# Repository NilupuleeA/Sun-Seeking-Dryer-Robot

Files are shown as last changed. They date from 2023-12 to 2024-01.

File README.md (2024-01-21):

# Sun-Seeking-Dryer-Robot

This is a group project done under the module EN1190 Engineering Design project, Semester 2 of the Department of Electronic and Telecommunication Engineering.

1. Introduction
   
- This dryer is designed to transform the conventional approach to drying spices, shoes, and other items in both rural and urban households. By integrating an advanced sun tracking system using Light-Dependent Resistors (LDR) sensors, this dryer autonomously follows the sun's movement throughout the day, ensuring optimal exposure to sunlight for efficient and eco-friendly drying.

2. Key Features
- Automatic Sun Tracking: The dryer utilizes cutting-edge LDR sensors to precisely follow the sun's position, optimizing the drying process without manual intervention.

- Energy-Efficient: This system utilizes sunlight, a renewable energy source, reducing environmental impact and providing a sustainable solution for households.

- Effortless Drying: The Sun Seeking Dryer simplifies the drying process, making it accessible to everyone in the community.

https://github.com/NilupuleeA/Sun-Seeking-Dryer-Robot/assets/153465850/cd82b63b-5a86-44f9-a196-c00ea6002b2a

Final_Product

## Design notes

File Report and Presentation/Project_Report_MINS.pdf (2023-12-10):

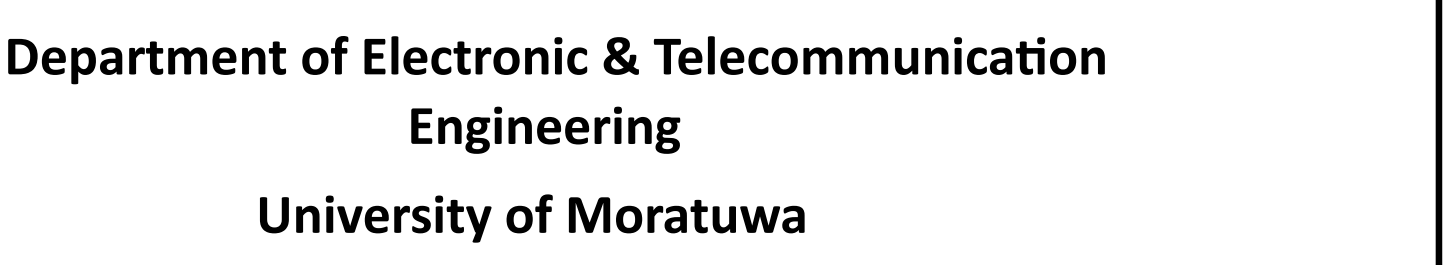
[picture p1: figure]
Engineering; University of Moratuwa

## Department of Electronic & Telecommunication

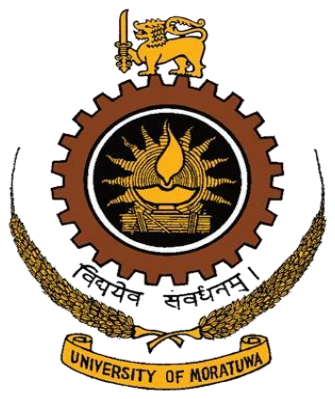
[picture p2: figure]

## EN 1190 - Engineering Design Project

Final Project Report

## Sun Seeking Dryer Robot – Team MINS

Group members:

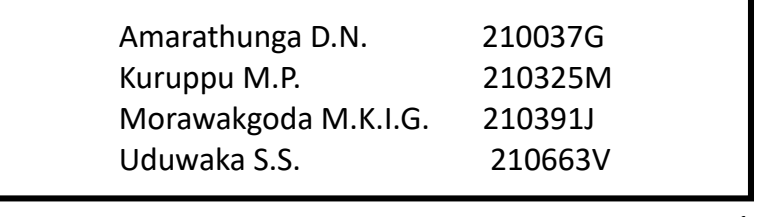
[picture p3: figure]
Amarathunga D.N.; Kuruppu M.P.; Morawakgoda M.K.I.G.; Uduwaka S.S.

# INDEX

## 1 Introduction

In today's fast-paced world, where busy schedules and unpredictable weather conditions often hinder household chores, the need for efficient and automated solutions becomes evident. Drying various materials, such as seeds, spices, clothes, and shoes, using sunlight, is often time-consuming and unreliable due to weather fluctuations. To address this challenge, our project aims to develop an automatic sun-seeking dryer that optimizes the drying process through sun tracking technology.

### 1.1 Problem description

Households, especially those in rural areas with limited access to electricity, face difficulties in efficiently drying materials. Conventional sunlight-based drying methods are subject to weather conditions and require manual intervention for effective drying. Our project seeks to create an innovative solution that eliminates these challenges by automating the drying process.

### 1.2 Motivation

The motivation behind this project lies in enhancing the overall quality of life for individuals by providing a solution that optimizes an essential domestic task. By automating the drying process, we aim to relieve the burdens faced by households, enabling them to focus on other tasks. This project aligns with the broader societal push toward sustainable practices and resource conservation, as the sun-seeking dryer utilizes a renewable energy source.

We conducted a survey in the initial stage to gather some information about the drying process. After analyzing a sample of 100 people, we have concluded some justifications for the project.

According to the survey most of the people know the traditional methods of drying materials. It was obvious that most of the people use different drying methods to dry their clothes, shoes, and seeds in their day-to-today lives. By analyzing the survey, we could conclude that the drying methods are essential for the daily works because most of the people who responded to the survey have submitted that they are using the methods of drying for domestic purposes very frequently. The below pie chart shows how often people dry materials for domestic purposes according to the survey. Also, we decided to collect data about the issues the people are facing with the traditional methods of drying materials. According to the results, the main issues of the traditional methods are the rain, cloudy days, and the changes of humidity. Here are the results that we got. A waste of time, taking longer time than expected, bad smell, reducing the quality of the final product, not being able to dry properly, inability to attend at the right time and to the right standard, were the main issues they have been faced.

### 1.3 Our Solution

The team of MINS decided to take the burden on to their shoulders and decides to find a solution. The sun seeking dryer robot is the ultimate result of this. When the sun seeking dryer robot is kept in a position where the intensity of the sunlight is low it moves to a position where the intensity of sunlight is higher than the previous place.

## 2 Technical feasibilities

Our project of designing an automatic system that follows the sun to dry materials is technically feasible. This system can be built using a set of sensors, microcontrollers, and mechanical components such as motors, wheels etc.

### 2.1 Sensors

The system would require a few essential sensors, including LDRs, to monitor the sunlight intensity and ultrasonic sensors to identify barriers on the way. These sensors are readily available and affordable in the market, and the required performance targets can be met without any difficulty.

For this system we used 4 LDR to cover the four directions. Also, we used 2 ultrasonic sensors in the forward and backward directions to identify the barriers when moving.

### 2.2 Microcontroller

The microcontroller is the brain of the system that controls the entire operation of the automatic driving system. Microcontrollers are widely used in various industrial applications, and they can handle the necessary calculations and data processing required for this project. Moreover, the availability and affordability of microcontrollers make it a feasible option.

For this system we used ATMEGA 328 micro controller.

### 2.3 Mechanical components

The mechanical components, including motors and wheels, are also readily available and can be used to ensure that the system moves smoothly and accurately. These components can be controlled by the microcontroller, which ensures that the system moves in the right direction and at the right speed.

In conclusion, the technical feasibility of the proposed project of designing an automatic system that follows the sun to dry materials is high, and all the necessary resources and performance targets are readily available and can be met.

## 3 Product Architecture

### 3.1 Block Diagram Abstraction of the Device

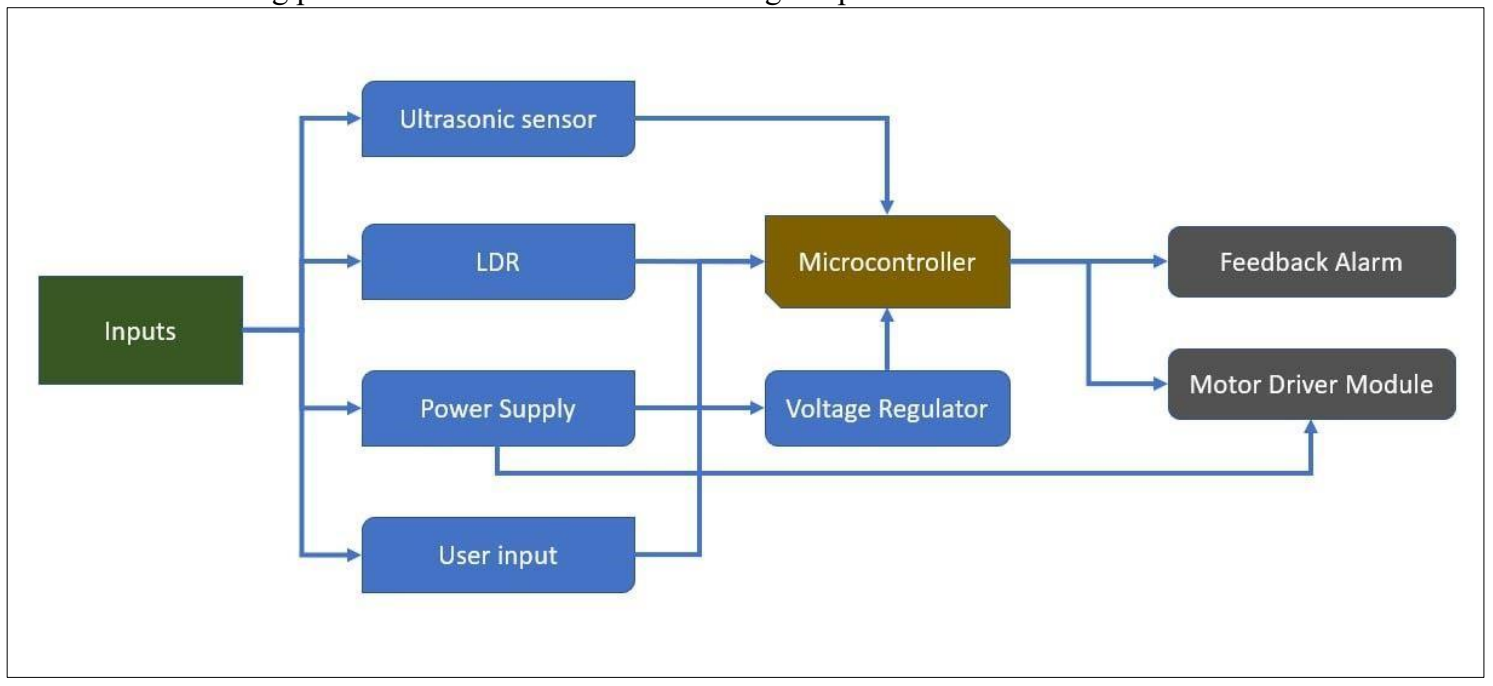
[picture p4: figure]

The following product architecture was used during the process.

### 3.2 Functionality of the Blocks

### - Power Supply Management

The power supply management for this device utilizes two 3.7V rechargeable batteries, which are regulated down to 5V using a voltage regulator.

### - User Input

An on/off switch is manually controlled by the user to switch the entire system on and off.

### - LDR

The device is equipped with four LDRs that are used to detect and measure the intensity of sunlight in all four directions. This information is used to make decisions about the device's operation and to adjust its movements and functions, as necessary.

### - Ultrasonic Sensor

Two ultrasonic sensors are also incorporated into the device to measure the distance to obstacles and prevent collisions while the device is in use.

### - Microcontroller

The microcontroller is responsible for processing all these inputs and controlling the device's overall operation.

### - Feedback Alarm

If all sides are dark, a feedback alarm is triggered to inform the user of this situation. For this purpose we used a buzzer.

### - Motor Driver Module

The device is equipped with a motor driver module that allows system to rotate its wheels and move throughout its environment.

## 4 Product enclosure

### 4.1 Solid work design

The enclosure was designed by using ‘Solid Works’. It is made by the material ‘PLA’

The enclosure contains 2 major parts. They are the top and the bottom part. The bottom part was design in such a way that it contains holes for four wheels, two ultrasonic sensors, four tubes for the LDR, switch, charging port.

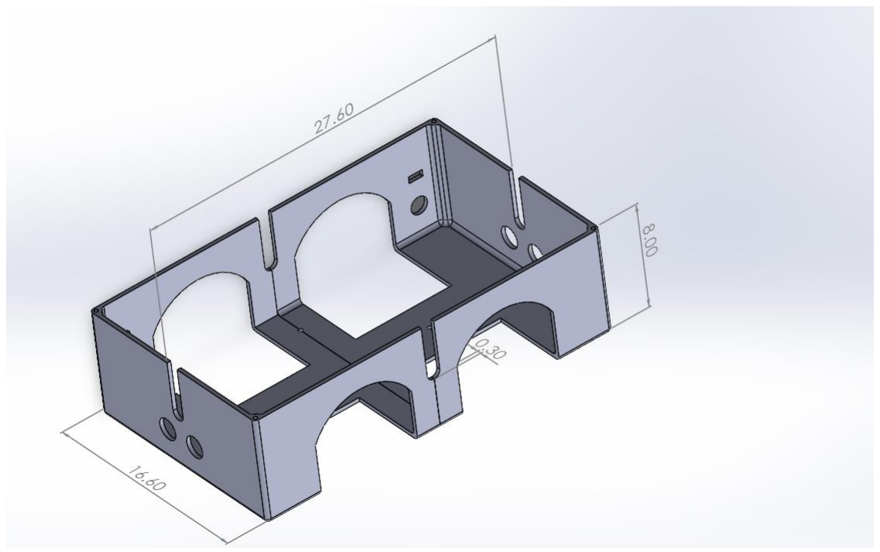
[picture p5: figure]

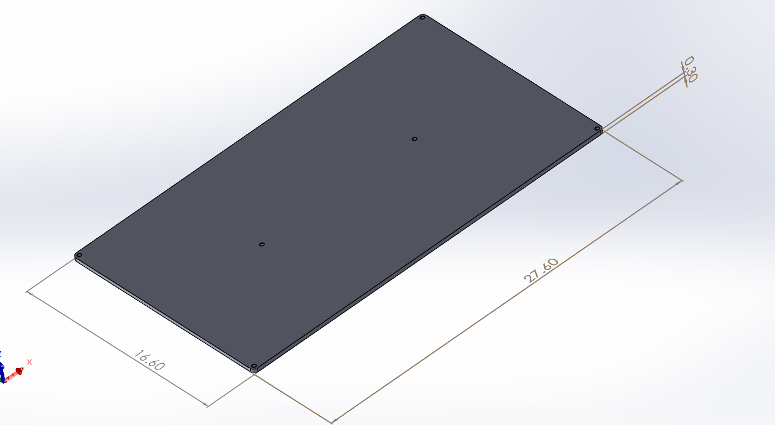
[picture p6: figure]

The tray to hold materials such as grains was made by a light metal to enhance the tendency for absorbing sunlight to make the drying process more rapid than the normal way. The reason for not selecting iron as the material for designing the tray is the tendency of iron to corrode when imposing sunlight, wind, and humidity climatic parameters and it will cause to reduce the quality of the drying material.

Also, we had to keep a distance between the metal tray and the top part in order to avoid unwanted heating of the circuit.

The following diagram shows how the final design looks like.

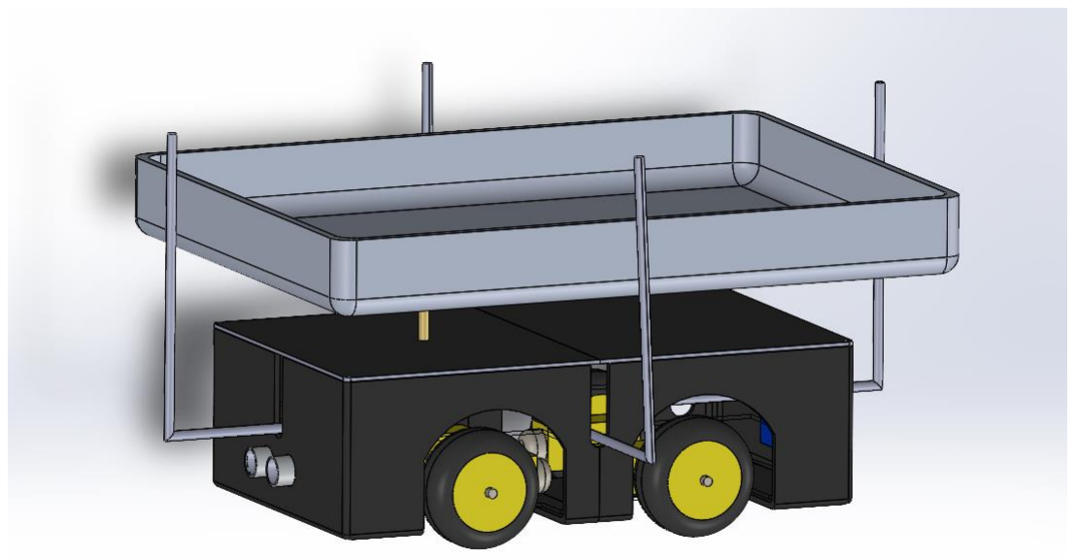
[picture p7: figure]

## 5 Circuit Diagram

### 5.1 Altium Schematic Diagram

The following schematic diagram has been created using Altium.

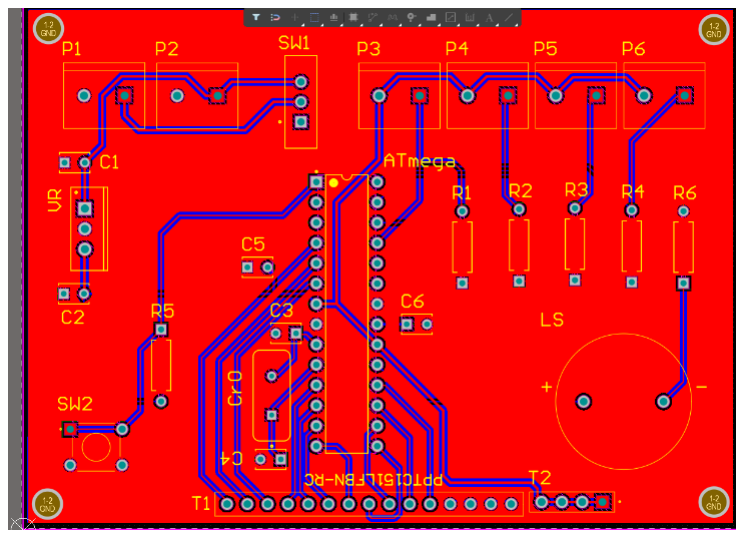
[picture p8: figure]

After Soldering the components

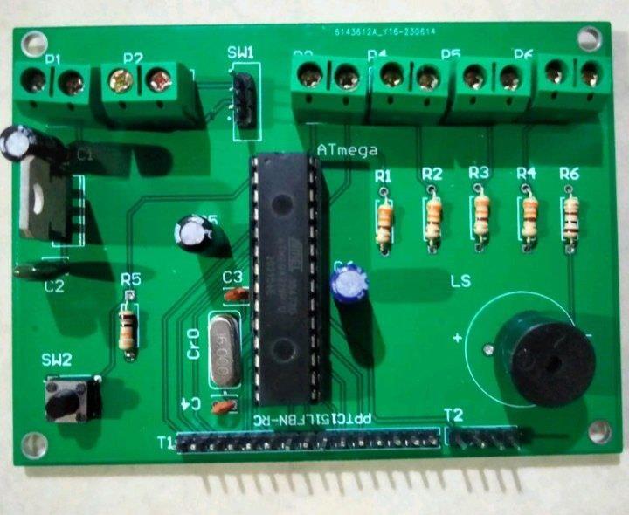
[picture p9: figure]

### 5.2 ATmega Circuit Stimulation

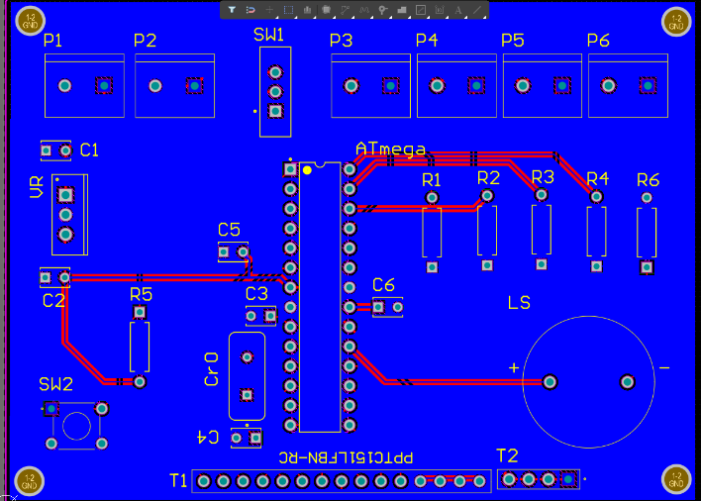
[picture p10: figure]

The ATmega circuit has been stimulated using virtual tools. It is unclear what specific tools were used or what the results of the stimulation were, but it can be assumed that progress has been made on this aspect of the project.

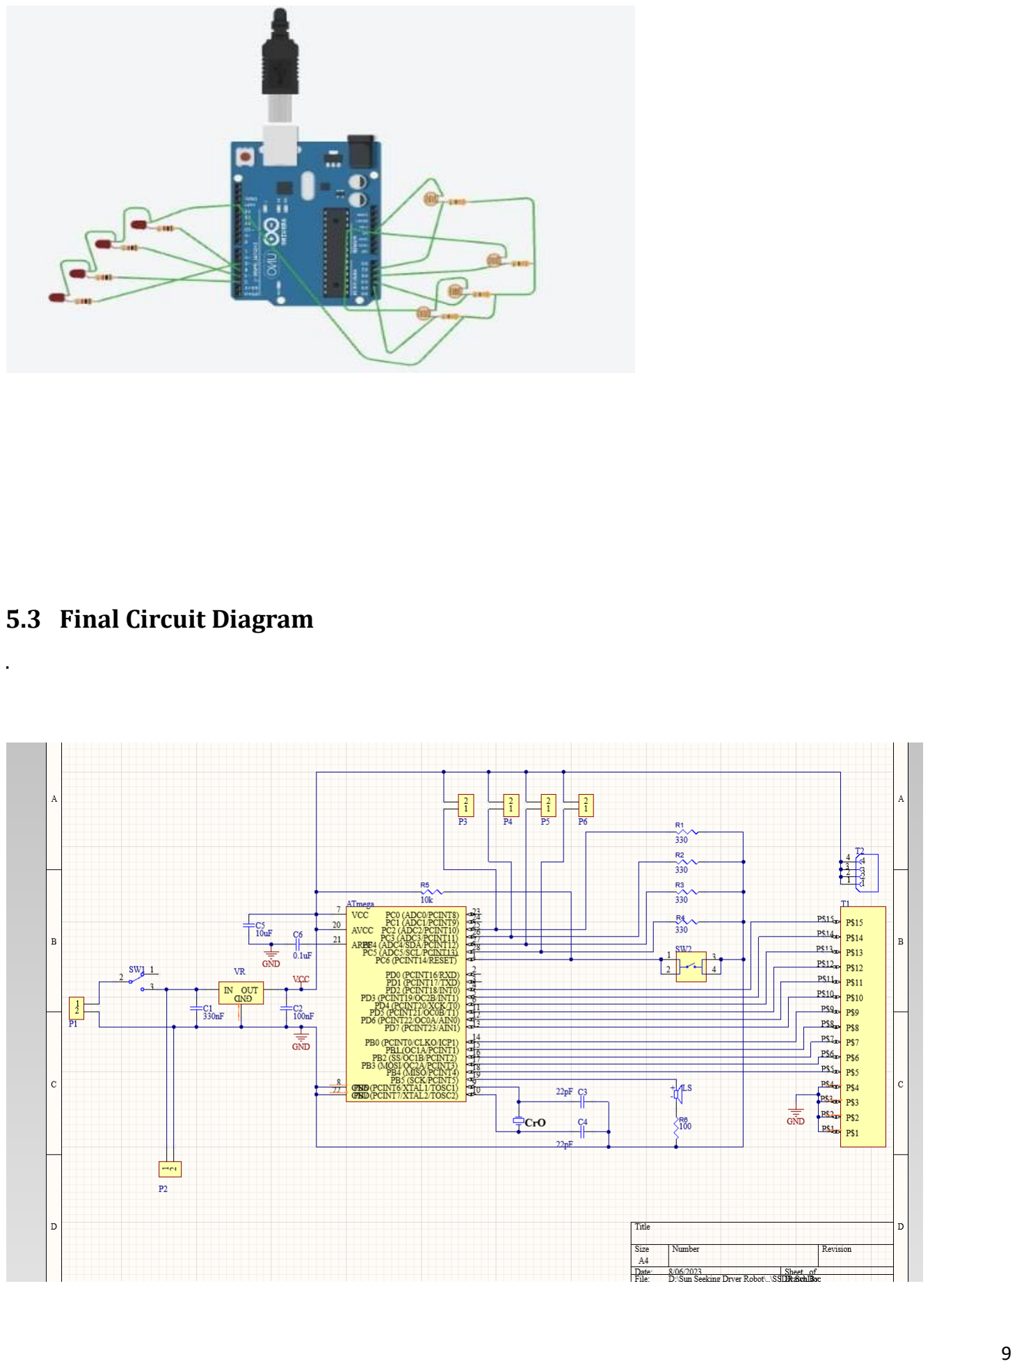
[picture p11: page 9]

### 5.3 Final Circuit Diagram

6 How it works.

### 6.1 Logical part of LDRs

The output values of the LDR varies from 0-1023. Hence if all the values are below 450 then it makes a sound by the buzzer. If all the values are above 650 then it is stable and it remains at a stationary position. If the value is between the values 450-650, then it takes the difference between two consecutive LDRs and if there is a difference then it moves opposite to the dark side (where the intensity of the sun light is low.) Also, priority is given to the forward and back word directions.

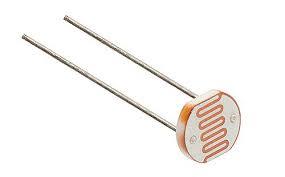
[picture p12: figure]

### 6.1 Logical part of Ultra-sonic Sensors

If there is an obstacle in the moving direction with a distance less than 40 cm then it stops and moves to the direction where the intensity of the sun light is higher among the remaining directions

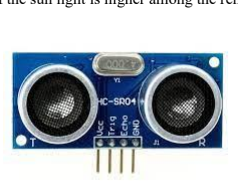
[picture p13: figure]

## 7 Business Model

### 7.1 Marketing and Sales

- Identify target audience.
The target audience for the sun seeking dryer robot could be busy individuals, families, and small business owners who need to dry materials such as seeds, spices, clothes, shoes and so on.
- Create a brand name.
Create a brand name that is catchy, easy to remember, and represents the product's features and benefits. So, we choose our brand name as ‘Selfodryer’

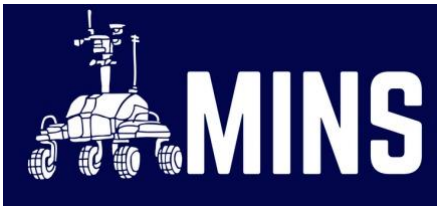
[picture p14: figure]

- Social media presence
Create a social media presence to generate interest and attract potential customers. Also, it will showcase the features and benefits of the product. Also, we can publish some posts that show how the sun seeking dryer robot works, how it can save time and energy, and how it can improve the drying process.
- Offer product discounts.
Offer discounts to early adopters (customers) to encourage them to try the product and share their experiences with others.
- Attending trade shows and exhibitions.
Attend trade shows and exhibitions related to home appliances, gardening, and household products to showcase the sun seeking dryer robot to potential customers and distributors.
- Provide excellent customer service.
Provide excellent customer service to ensure that customers are satisfied with the product and their experience with the company. This will lead to positive reviews and word-of-mouth marketing. Also, we are planning to conduct a survey among the customers once a year.

Overall, the marketing plan will be focused on highlighting the benefits of the sun seeking dryer robot, such as saving time and energy, improving the drying process, and providing a convenient solution for busy individuals and families. We will also be emphasizing the product's innovative and eco-friendly features, which will appeal to environmentally conscious customers.

### 7.2 After-Sale Service

After-sale service is a critical aspect of any product, therefore we had to focus on the after sales service of the sun-seeking dryer robot. It ensures that customers are satisfied with their purchase, and any issues or concerns are addressed in a more efficient way, which enhances customer loyalty. And it will have a good effect for the customers to repeat the business. Here are some considerations for after-sale service for the sun-seeking dryer robot.

- Clear Warranty
We are planning to offer a clear and concise warranty of six months. That outlines the terms and conditions, including what they cover. This will help customers understand their rights and what to expect in case of any issues.
- User Manual:
Provide an understandable user manual that includes detailed instructions for setting up, using, and maintaining the sun-seeking dryer robot. We are planning to include troubleshooting tips and contact information for customer support.
- Customer Support:
Offer reliable and quick customer support through multiple channels, such as email, Facebook and Instagram.
- Replacement Parts
Replacement parts are readily available and affordable for customers in case any part of the sun-seeking dryer robot needs to be repaired or replaced.
- Feedback Mechanism:
We have set up a feedback mechanism for customers to report any issues or suggestions for improving the product. (Customer survey, Online feedback form). Also, we have planned to enable a QR code system where the customers can submit the problems and issues whenever they need.

By implementing these after-sale service considerations, customers will have a positive experience with the sun-seeking dryer robot, and our brand ‘Selfodryer’ will be able to establish a strong reputation for quality and customer support.

## 8 Project Budget

### 8.1 Cost of Modules and Components

Component | Unit price (LKR) | Quantity | Amount (LKR)
Wheel with DC gear
motor | 280 | 4 | 1120
ATMEGA 328P
microcontroller | 1800 | 1 | 1800
Ultrasonic sensors
(Sona sensers) | 280 | 2 | 560
16 MHz oscillator | 40 | 1 | 40
Motor driver | 500 | 1 | 500
BMS | 500 | 1 | 500
IC holder | 8 | 1 | 8
3.7V 4000MA battery | 450 | 2 | 900
Battery holder - 2 cell | 120 | 1 | 120
220 Ω resistor | 3 | 4 | 12
330 Ω resistor | 3 | 4 | 12
1kΩ resistor | 3 | 4 | 12
LDR | 15 | 4 | 60
0.1 µF capacitor | 2 | 1 | 2
22 pF capacitor | 5 | 2 | 10
0.33 µF capacitor | 5 | 1 | 5
ON/OFF slide switch | 50 | 1 | 50
7806 voltage
regulators | 60 | 1 | 60
Tray | 930 | 1 | 930
| | Total(LKR) | 6701

### 8.2 Product Price

Price of components | Rs.6701
PCB printing | Rs.580
3D printing | Rs.3240
Other expenses | Rs.150
Total Expense | Rs.10671
Profit | Rs.4328
Total Product Price | Rs.14999/=

## 9 Task Allocation

Member | Tasks Allocated
Kuruppu M. P. | Coding, Circuit design, Assembling the components
Uduwaka S.S. | Coding, Circuit design, Assembling the components
Amarathunga D. N. | PCB design, Assembling the components
Morawakgoda M. K. I. G. | Enclosure design, Assembling the components

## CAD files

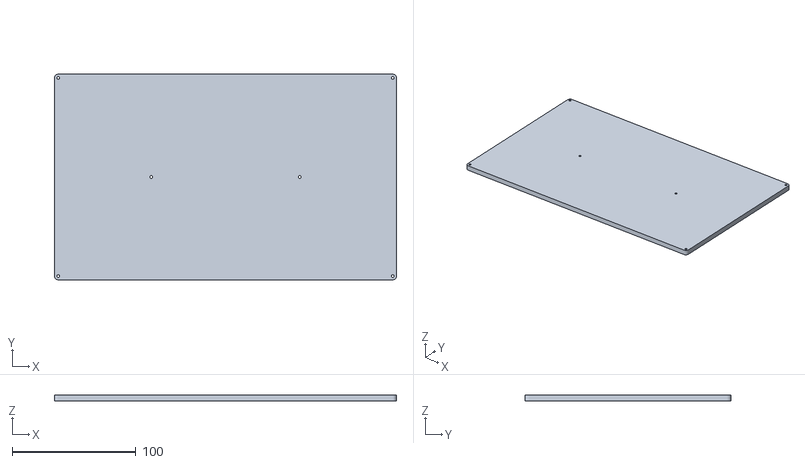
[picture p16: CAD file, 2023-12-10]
Enclosure/top_final.STL
276.0 x 166.0 x 5.00

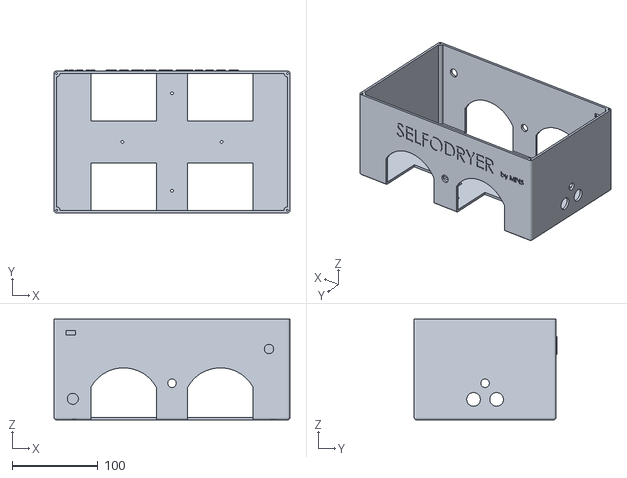
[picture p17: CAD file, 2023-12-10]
Enclosure/bottom_part.STL
276.0 x 167.0 x 118.0

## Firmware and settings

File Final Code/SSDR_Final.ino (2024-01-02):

// Include the SoftwareSerial library for serial communication
#include <SoftwareSerial.h>
SoftwareSerial mySerial(11, 12);

// Define pin assignments for ultrasonic sensors
uint8_t TRIG_PIN1 = 2;  
uint8_t ECHO_PIN1 = 3;
uint8_t TRIG_PIN2 = 4;
uint8_t ECHO_PIN2 = 5;

// Define pin assignments for motor outputs
uint8_t OUTPUT_1 = 6;  //Right forward
uint8_t OUTPUT_2 = 7;  //Right backward
uint8_t OUTPUT_3 = 9;  //Left forward
uint8_t OUTPUT_4 = 10;  //Left backward

// Define pin assignment for buzzer
uint8_t BUZZER = 13;

// Declare variables for LDR values, distance measurements, and threshold
float ldr1, ldr2, ldr3, ldr4, x, distance1, distance2;
int threshold = 650;

void setup() {
  // Set pin modes for motor outputs
  pinMode(OUTPUT_1, OUTPUT);
  pinMode(OUTPUT_2, OUTPUT);
  pinMode(OUTPUT_3, OUTPUT);
  pinMode(OUTPUT_4, OUTPUT);

  // Set pin modes for ultrasonic sensors
  pinMode(TRIG_PIN1, OUTPUT);
  pinMode(ECHO_PIN1, INPUT);
  pinMode(TRIG_PIN2, OUTPUT);
  pinMode(ECHO_PIN2, INPUT);

  // Set pin modes for buzzer
  pinMode(BUZZER, OUTPUT);

  // Initialize serial communication for debugging and SoftwareSerial for SIM800L module
  Serial.begin(9600);
  mySerial.begin(9600);
}

// Function to read distance using ultrasonic sensor
float readDistanceCM(int trig, int echo) {
  digitalWrite(trig, LOW);
  delayMicroseconds(2);
  digitalWrite(trig, HIGH);
  delayMicroseconds(10);
  digitalWrite(trig, LOW);
  int duration = pulseIn(echo, HIGH);
  delay(100);
  return duration * 0.034 / 2;
}

// Function to send a message using the SIM800L module
void Sendmessage(){
  mySerial.println("AT+CMGF=1");
  delay(1000);
  mySerial.println("AT+CMGs=\"+94762811062\"\r");
  delay(1000);
  mySerial.println("Selfodryer: I'm in the extreme darkness");
  delay(100);
  mySerial.println((char)26);
  delay(1000);
}

// Function to control robot movements based on sensor readings
void movements() {
  // Check if all LDR values are below or equal to 100 (indicating extreme darkness)
  if (ldr1 <= 100 && ldr2 <= 100 && ldr3 <= 100 && ldr4 <= 100) {
    stop();
    digitalWrite(BUZZER, HIGH);
    Sendmessage();  // Function to send a message
    delay(2000);
    digitalWrite(BUZZER, LOW);
    delay(3000);
  }
  // Check if there a significant difference between adjacent LDR values
  else if (abs(ldr1 - ldr2) > 80 || abs(ldr3 - ldr4) > 80) {
    // Determine the minimum LDR value among all
    x = min(ldr1, min(ldr2, min(ldr3, ldr4)));

    // Check if any LDR value is below or equal to the threshold
    if (ldr1 <= threshold || ldr2 <= threshold || ldr3 <= threshold || ldr4 <= threshold) {
      // Adjust robot movements based on LDR and ultrasonic sensor readings
      if (x == ldr1) {
        // Check if distance from ultrasonic sensor 1 is greater than 40 cm
        if (distance1 > 40) { forward(); }
        else { stop(); }
      }
      else if (x == ldr2) {
        // Check if distance from ultrasonic sensor 2 is greater than 40 cm
        if (distance2 > 40) { backward(); }
        else { stop(); }
      }
      else if (x == ldr3) {
        // Turn right
        right();
      }
      else if (x == ldr4) {
        // Turn left
        left();
      }
    } 
    else {
      // Stop the robot if all LDR values are above the threshold (indicating sufficient light conditions)
      stop();
    }
  }
  else {
    // Stop the robot if the lighting conditions are sufficient 
    stop();
  }
}


// Functions to control robot movements
void forward() {
  digitalWrite(OUTPUT_1, HIGH);
  digitalWrite(OUTPUT_2, HIGH);
  digitalWrite(OUTPUT_3, LOW);
  digitalWrite(OUTPUT_4, LOW);
}

void backward() {
  digitalWrite(OUTPUT_1, LOW);
  digitalWrite(OUTPUT_2, LOW);
  digitalWrite(OUTPUT_3, HIGH);
  digitalWrite(OUTPUT_4, HIGH);
}

void right() {
  digitalWrite(OUTPUT_1, HIGH);
  digitalWrite(OUTPUT_2, LOW);
  digitalWrite(OUTPUT_3, LOW);
  digitalWrite(OUTPUT_4, HIGH);
}

void left() {
  digitalWrite(OUTPUT_1, LOW);
  digitalWrite(OUTPUT_2, HIGH);
  digitalWrite(OUTPUT_3, HIGH);
  digitalWrite(OUTPUT_4, LOW);
}

void stop() {
  digitalWrite(OUTPUT_1, LOW);
  digitalWrite(OUTPUT_2, LOW);
  digitalWrite(OUTPUT_3, LOW);
  digitalWrite(OUTPUT_4, LOW);
}

void loop() {
  // Read LDR values and ultrasonic sensor distances
  ldr1 = analogRead(2);
  ldr2 = analogRead(3);
  ldr3 = analogRead(4);
  ldr4 = analogRead(5);
  distance1 = readDistanceCM(TRIG_PIN1, ECHO_PIN1);
  distance2 = readDistanceCM(TRIG_PIN2, ECHO_PIN2);

  // Print sensor values for debugging
  Serial.println(distance1);
  Serial.println(distance2); 

  // Delay before calling the movements function
  delay(100);
  movements();
}

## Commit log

2024-07-09 new changes
    [bottom_part.STL, top_final.STL]
2024-07-09 Revert "new changes"
    This reverts commit f7a21dc6f750d293d16d527747e7413fdc46e789.
    [bottom_part.STL, top_final.STL]
